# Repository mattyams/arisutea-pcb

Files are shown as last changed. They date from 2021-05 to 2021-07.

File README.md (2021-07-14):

# Arisutea - Arisu Keyboard PCB with More Modifications...now with MORE!
<p align="center">
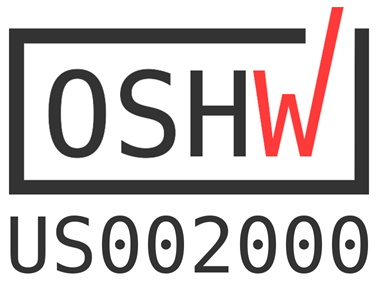
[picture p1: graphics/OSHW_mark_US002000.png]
  
</p>

### Arisutea Keyboard Variants
- [STM32](https://github.com/mattyams/arisutea-pcb-stm32) - Prototypes Received. STM32F072 MCU, board is being tested.
- [SK6812MiniE](https://github.com/mattyams/arisutea-pcb-rgb) - In Progress. PCB designed, just need to do some QC.
- [Bluetooth](https://github.com/mattyams/arisutea-pcb-bt) - In Progress. Initial design for the PCB is ongoing, need to research more on the MCU and batteries.

## Disclaimer: Use these files at your own risk.
アリステア PCB designed using KiCad. The layout was originally created by FateNozomi, inspired by Lyn's EM7 and TGR Alice with some modification. The layout was then modified by CorruptedJef and robotictomato to add USB-C, ESD and to shift/add some keys. This inspired me to modify the layout further by adding the ability to swap your switches out whenever you want and to make some keys a little more permenant. I have designed many boards in the past but never a keyboard so this is my first crack at it and I figured why not go all out? If you notice any issue please open an issue and we can discuss!

Since the layout has been modified yet again I decided to give the project a new name, Arisutea, which translates to Alistair. Obviously keeping the theme running here. 

Check out the iBOM [here](https://htmlpreview.github.io/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)! This was generated with [InteractiveHtmlBom](https://github.com/openscopeproject/InteractiveHtmlBom)!

Key modifications to the PCB:
- Added in Kailh Hotswap sockets.
- Addition of full backspace position, connected to switch 59 (row 0, column 13).
  - Removed switch 63 and repositioned switch 59 to add full backspace position.
- USB-C ESD rework.
- Added underglow LED strip support (v0.6+)
- Added LED indicators for CAPS and NUM lock as well as layer. (v0.6+)
- Updated JSON layout file for this particular keyboard.
- Original mounting holes have been returned to their rightful place. The idea of widening them was good at the time for FR4 plates, but not very practical. I am redesigning the case to allow for brass inserts and standoffs to be installed so the PCB will be nice and snug. More on that later. FR4 plates still will work but you will have to drill the holes out manually. If you take this route....go forth cautiously adventurer.

Renders generated by [Tracespace](https://github.com/tracespace/tracespace).
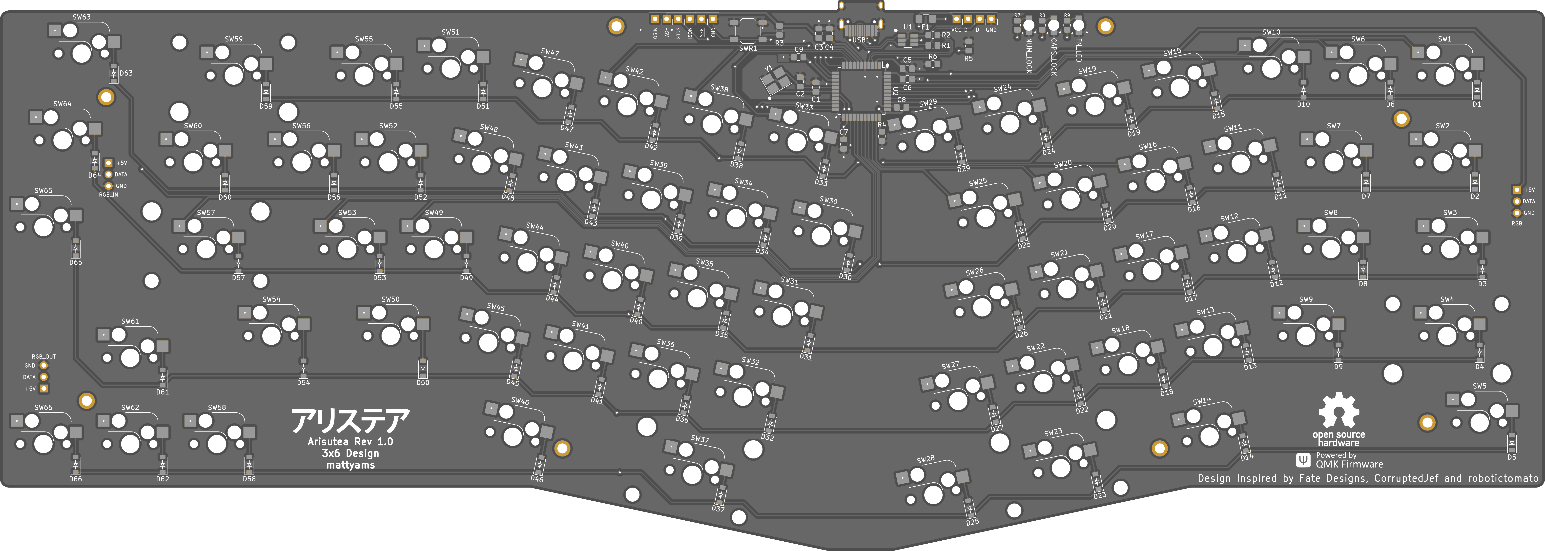
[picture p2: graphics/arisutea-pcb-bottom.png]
Arisutea

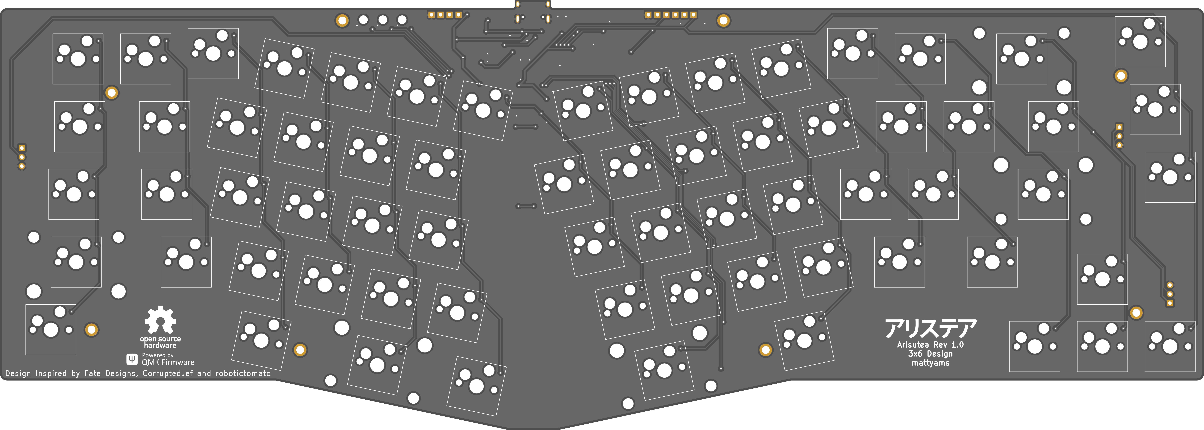
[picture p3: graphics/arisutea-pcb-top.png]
Arisutea-top

Arisutea-assembled
v0.6+
Arisutea-v0.6
Arisutea-v0.6-back

Just some recent builds...
Arisutea-builds
Arisutea-builds
Arisutea-builds

Messing around with different switches.
Arisutea-switches

# QMK Firmware
This can be located in the [firmware](https://github.com/mattyams/arisutea-pcb/tree/master/firmware) folder. 

# Case Files for Ponoko

Case files are updated to reflect changes to the full backspace on switch 59 and can be found in the hardware folder under [arisutea-case](https://github.com/mattyams/arisutea-pcb/tree/master/hardware/arisutea-case).  The case I ordered with these changes just came in this week (3/6/2021) and it works very well with the changes I made to the full backspace and addition of the stablizer on the prototypes designed by CorruptedJef and robotictomato. There is now a "boxed" version of the case that I have made that is designed to work with some wrist rests that do not have the ortho shape AND case files for version 0.6+ PCBs that include the indicator LEDs, I have not ordered/tested these but will soon.

Ponoko-case-1
Ponoko-case-2
Ponoko-case-3
Ponoko-case-4

# FR4 Plates and Case

Additionaly I have created files for FR4 plates to be made and used with this layout. These can be found in the hardware folder under [FR4_Plates](https://github.com/mattyams/arisutea-pcb/tree/master/hardware/FR4_Plates). The plates are designed to fit with the full backspace and non-stepped capslock. That being said, these will not work on the original Fate Designs PCB. No plans to create plates for the LED indicators on the v0.6+ PCBs. NOTE FOR v0.6.3+ PCBs! FR4 plates still will work but you will have to drill the holes out manually. If you take this route....go forth cautiously adventurer.

FR4-Plates-1
FR4-Plates-2
FR4-Plates-3
FR4-Plates-6

## Exceprts from original designer, FateNozomi:

Key differences:
- Removed the extra [B] key on the right half and shifted the [NM,.?] row to the left by 0.25U.
- Shifted the 3 keys to the right and added arrow keys.
- Tweaked the bottom so that the 1.5U keys doesn't protrude out a little.

Shifting the [NM,.?] row to the left by 0.25U required quite some work on the arrangement of keys for the right half.
As a result, this does not give the same typing experience as Lyn's EM7 and TGR Alice.
Lyn's EM7 and TGR Alice uses the home row as the center point to vertically align both halves while I used the number row instead.
Due to the nature of staggered keyboards, aligning using the number row resulted in the home row not being aligned.

Disclaimer: Use these files at your own risk.

## Gerber Files
Download the gerber files under [releases](https://github.com/mattyams/arisutea-pcb/releases).

## PCB Assembly
For the components required, you may refer to the bill of materials included along with the release as reference or load up the design file in KiCad.
All the components can be soldered using a regular soldering iron, though soldering the USB-C receptacle might be the biggest hurdle. I have made an adjustment to the USB footprint to allow for a little more error when handsoldering. POS files have been removed due to the overwhelming amount of compatibility issues of placement and selection. The BOM will remain for part numbers from LCSC and board placement.

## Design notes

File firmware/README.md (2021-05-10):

# QMK Firmware for Arisutea Keyboard

There are 2 files here and are described below:
- arisutea_rev2_default.hex - this is for the rev06 board that has the indicators and underglow LEDs. It uses the default layout seen below.
- arisutea_rev1_default.hex - this is for any board prior to rev06 that does not have any LEDs on the board at all. It uses the default layout seen below.

Layer 0
Arisutea-Layer-0
Layer 1 - STD will not include RGB keys
Arisutea-Layer-1

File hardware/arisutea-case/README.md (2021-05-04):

# Acrylic Case for Arisutea
アリステア Acrylic Case design formatted ready for Ponoko with the kerf of the switch cutout set to 0.15mm. Case files are updated to reflect changes to the full backspace on switch 59 and have the Arisutea logo engraved on the case. Removed the matte file and adjust the normal so you can use it for either one.

A "boxed" version of the case that I have made is designed to work with some wrist rests that do not have the ortho shape. 

There are now case files for v0.6 PCB that include the indicator LEDs, I have not ordered/tested these but will soon.

These files are a fork from FateNozomi's Arisu case which can be found [HERE](https://github.com/FateNozomi/arisu-case)

## Disclaimer: Use these files at your own risk. 

Ponoko-case-1
Ponoko-case-2
Ponoko-case-3
Ponoko-case-4

## Case Pieces for Angled Case!

- Low Profile Angled Case (arisutea_lopro_case_P2_ponoko.eps)
- High Profile Angled Layer (Optional) (arisutea_hipro_layer_P2_ponoko.eps)

## Case Pieces for Boxed Case!

- Low Profile Boxed Case (arisutea_lopro_case_P2_boxed_ponoko.eps)
- High Profile Boxed Layer (Optional) (arisutea_hipro_layer_P2_boxed_ponoko.eps)

Boxed-case-proto-1
Boxed-case-proto-2

## Case Pieces for v0.6 with LED indicator cutouts - PROTOTYPE!
#### Case Pieces for Boxed Case!
- Low Profile Angled Case with LED cutouts (arisutea_lopro_case_indicators_P2_ponoko.eps)
- High Profile Angled Layer with LED cutouts (Optional) (arisutea_hipro_layer_indicators_P2_ponoko.eps)

#### Case Pieces for Boxed Case!
- Low Profile Boxed Case with LED cutouts (arisutea_lopro_case_P2_boxed_indicators_ponoko.eps)
- High Profile Boxed Layer with LED cutouts (Optional) (arisutea_hipro_layer_P2_boxed_indicators_ponoko.eps)

## Fabrication

- Upload the .eps file to Ponoko and select P2 size 3mm acrylic with the color of your choice.
    - Remember if choosing to use matte colors you must upload the matte file!

## Assembly

#### For Low Profile

Material | Quantity
------------ | -------------
M2.5 * 12mm | 4
M2.5 * 5mm | 12
[M2.5 HARWIN R25-1000602 standoff](https://www.harwin.com/products/R25-1000602/) | 8

#### For High Profile

Material | Quantity
------------ | -------------
M2.5 * 12mm | 12
M2.5 * 5mm | 4
[M2.5 HARWIN R25-1000602 standoff](https://www.harwin.com/products/R25-1000602/) | 8

This design uses M2.5 screws and standoffs. Feel free to modify the screw and standoff hole design accommodate your needs.  
The case will sit at an angle with the center portion protruding out so test the placement of your rubber bumpons before sticking them.

high profile side  
low profile side

Ponoko-case-3
Ponoko-case-4

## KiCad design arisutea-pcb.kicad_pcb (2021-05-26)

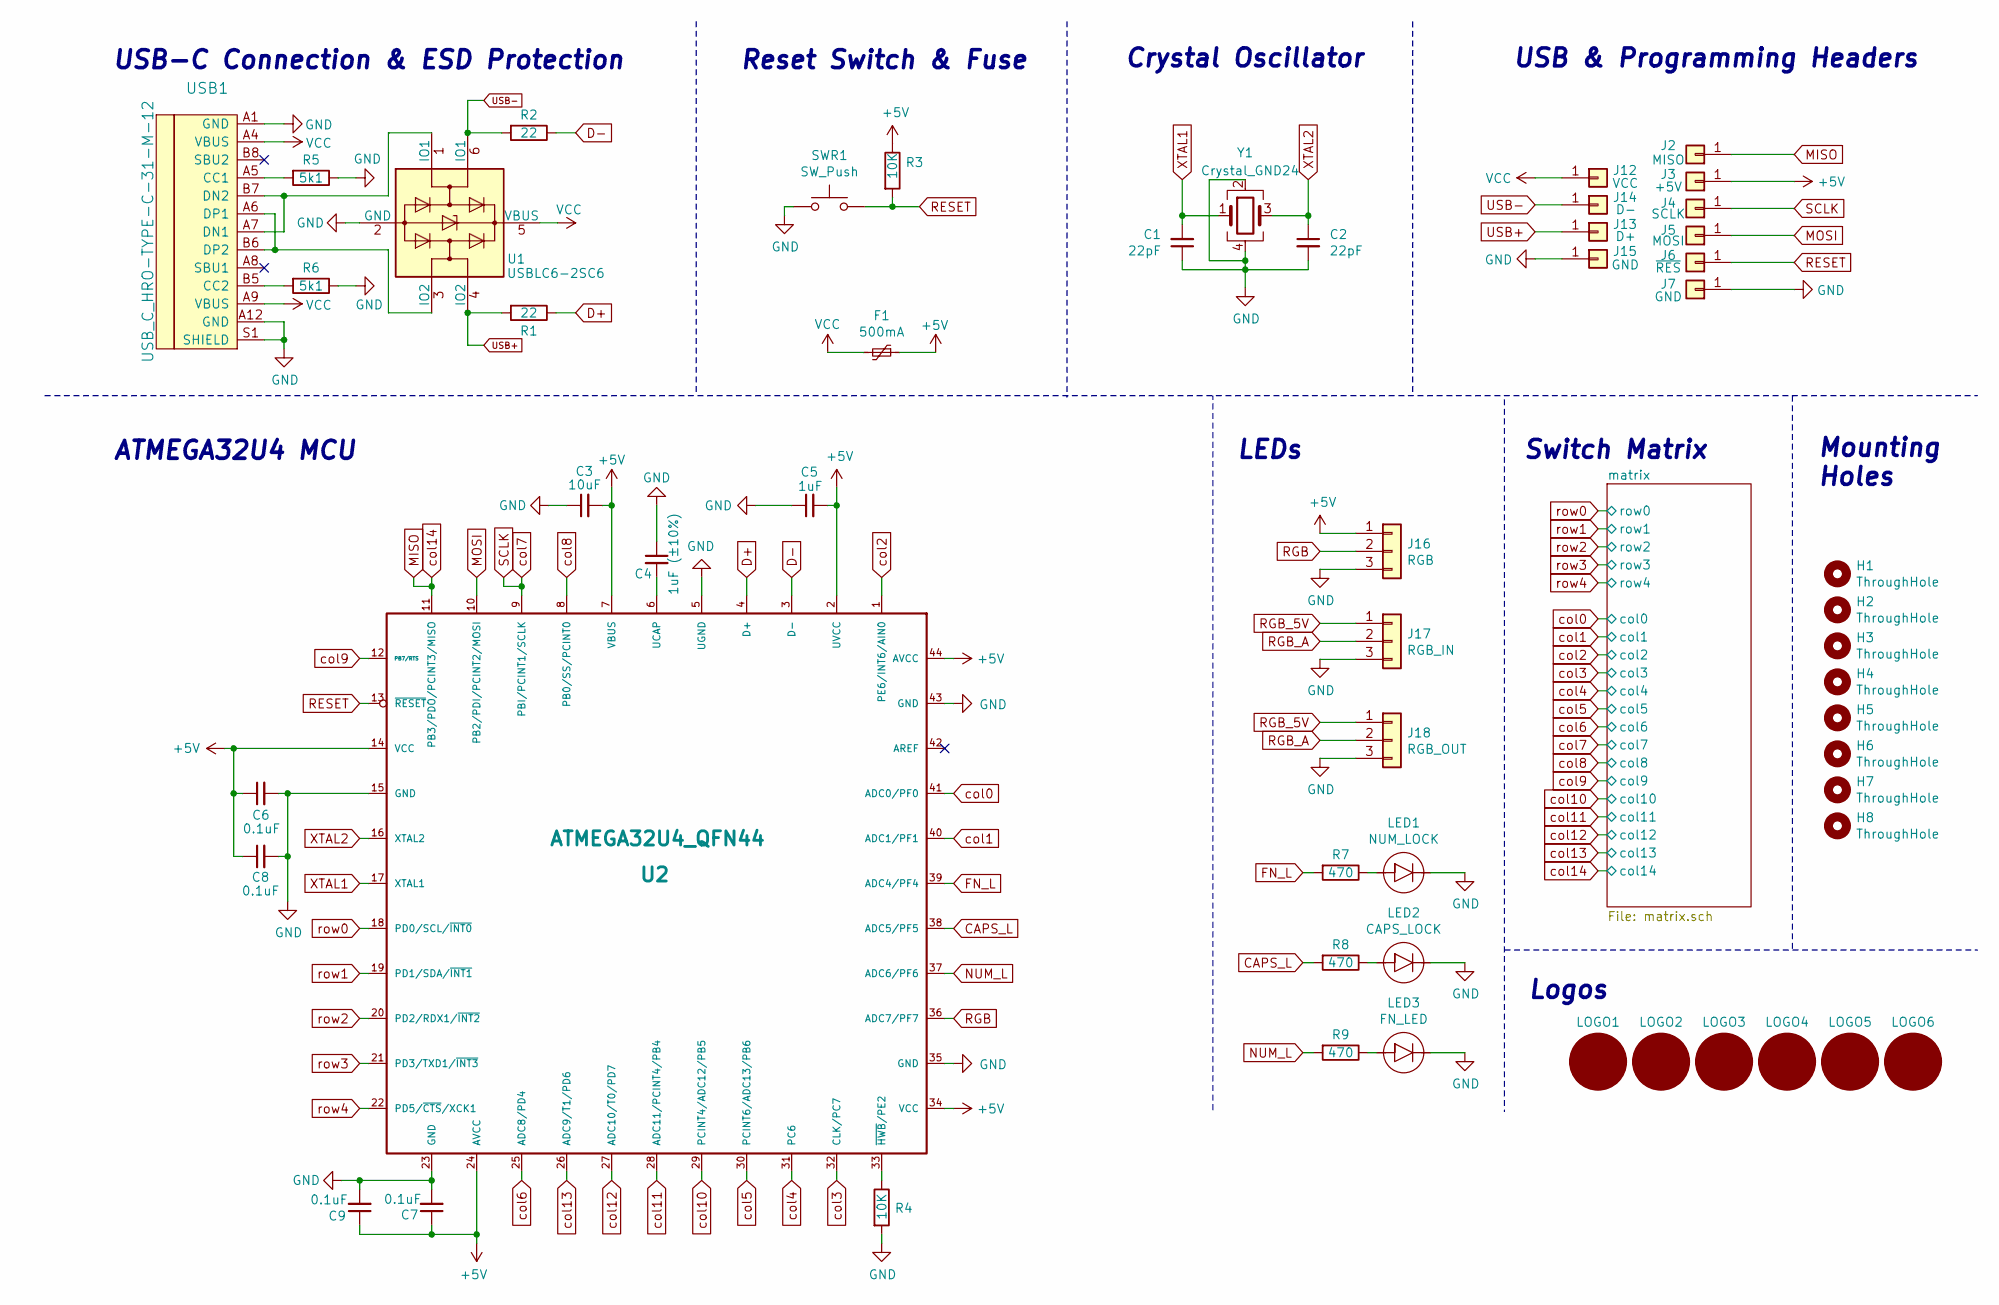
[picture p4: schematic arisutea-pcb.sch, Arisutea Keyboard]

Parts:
C1, C2: 22pF; C_0805_2012Metric_Pad1.18x1.45mm_HandSolder; LCSC C1804
C3: 10uF; C_0805_2012Metric_Pad1.18x1.45mm_HandSolder; LCSC C15850
C4: 1uF (±10%); C_0805_2012Metric_Pad1.18x1.45mm_HandSolder; LCSC C28323
C5: 1uF; C_0805_2012Metric_Pad1.18x1.45mm_HandSolder; LCSC C28323
C6, C7, C8, C9: 0.1uF; C_0805_2012Metric_Pad1.18x1.45mm_HandSolder; LCSC C28233
F1: 500mA; Fuse_1206_3216Metric_Pad1.42x1.75mm_HandSolder; LCSC C70068
H1, H2, H3, H4, H5, H6, H7, H8: ThroughHole; Generic-Mounthole
J2: MISO; PinHeader_1x01_P2.54mm_Vertical
J3: +5V; PinHeader_1x01_P2.54mm_Vertical
J4: SCLK; PinHeader_1x01_P2.54mm_Vertical
J5: MOSI; PinHeader_1x01_P2.54mm_Vertical
J6: ~RES~; PinHeader_1x01_P2.54mm_Vertical
J7, J15: GND; PinHeader_1x01_P2.54mm_Vertical
J12: VCC; PinHeader_1x01_P2.54mm_Vertical
J13: D+; PinHeader_1x01_P2.54mm_Vertical
J14: D-; PinHeader_1x01_P2.54mm_Vertical
J16: RGB; PinHeader_1x03_P2.54mm_Vertical
J17: RGB_IN; PinHeader_1x03_P2.54mm_Vertical
J18: RGB_OUT; PinHeader_1x03_P2.54mm_Vertical
LED1: NUM_LOCK; LED_IN-S124ARUW; LCSC C401114
LED2: CAPS_LOCK; LED_IN-S124ARUW; LCSC C401114
LED3: FN_LED; LED_IN-S124ARUW; LCSC C401114
LOGO1, LOGO2: arisutea_logo
LOGO3, LOGO4: QMK Logo; OSHW-Logo_11.4x12mm_SilkScreen
LOGO5, LOGO6: QMK_Logo_Light
R1, R2: 22; R_0805_2012Metric_Pad1.20x1.40mm_HandSolder; LCSC C17561
R3, R4: 10K; R_0805_2012Metric_Pad1.20x1.40mm_HandSolder; LCSC C17414
R5, R6: 5k1; R_0805_2012Metric_Pad1.20x1.40mm_HandSolder; LCSC C27834
R7, R8, R9: 470; R_0805_2012Metric_Pad1.20x1.40mm_HandSolder; LCSC C27834
SWR1: SW_Push; SW_SPST_TL3342; LCSC C318884
U1: USBLC6-2SC6; SOT-23-6_Handsoldering; LCSC C7519
U2: ATMEGA32U4_QFN44; TQFP-44_10x10mm_P0.8mm; LCSC C44854
USB1: USB_C_HRO-TYPE-C-31-M-12; USB_C_Receptacle_HRO_TYPE-C-31-M-12-HandSoldering; LCSC C319148
Y1: Crystal_GND24; Crystal_SMD_TXC_7M-4Pin_3.2x2.5mm_HandSoldering; LCSC C89371

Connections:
+5V: C3.2, C5.2, C6.1, C7.1, C8.1, C9.1, F1.1, J3.1, J16.1, R3.1, U2.2 (UVCC), U2.7 (VBUS), U2.14 (VCC), U2.24 (AVCC), U2.34 (VCC), U2.44 (AVCC)
CAPS_L: R8.2, U2.38 (ADC5/PF5)
D+: R1.1, U2.4 (D+)
D-: R2.1, U2.3 (D-)
FN_L: R7.2, U2.39 (ADC4/PF4)
GND: C1.1, C2.2, C3.1, C4.1, C5.1, C6.2, C7.2, C8.2, C9.2, J7.1, J15.1, J16.3, J17.3, J18.3, LED1.C, LED2.C, LED3.C, R4.2, R5.1, R6.1, SWR1.1, U1.2 (GND), U2.5 (UGND), U2.15 (GND), U2.23 (GND), U2.35 (GND), U2.43 (GND), USB1.A1 (GND), USB1.A12 (GND), USB1.S1 (SHIELD), Y1.2, Y1.4
MISO: J2.1, U2.11 (PB3/PDO/PCINT3/MISO); also elsewhere on the board
MOSI: J5.1, U2.10 (PB2/PDI/PCINT2/MOSI)
NUM_L: R9.2, U2.37 (ADC6/PF6)
unnamed: C4.2, U2.6 (UCAP)
unnamed: LED1.A, R7.1
unnamed: LED2.A, R8.1
unnamed: LED3.A, R9.1
unnamed: R4.1, U2.33 (~HWB~/PE2)
unnamed: R5.2, USB1.A5 (CC1)
unnamed: R6.2, USB1.B5 (CC2)
unnamed: U1.1 (IO1), USB1.A7 (DN1), USB1.B7 (DN2)
unnamed: U1.3 (IO2), USB1.A6 (DP1), USB1.B6 (DP2)
RESET: J6.1, R3.2, SWR1.2, U2.13 (~RESET~)
RGB: J16.2, U2.36 (ADC7/PF7)
RGB_5V: J17.1, J18.1
RGB_A: J17.2, J18.2
SCLK: J4.1, U2.9 (PBI/PCINT1/SCLK); also elsewhere on the board
USB+: J13.1, R1.2, U1.4 (IO2)
USB-: J14.1, R2.2, U1.6 (IO1)
VCC: F1.2, J12.1, U1.5 (VBUS), USB1.A4 (VBUS), USB1.A9 (VBUS)
XTAL1: C1.2, U2.17 (XTAL1), Y1.1
XTAL2: C2.1, U2.16 (XTAL2), Y1.3
col0: U2.41 (ADC0/PF0); also elsewhere on the board
col1: U2.40 (ADC1/PF1); also elsewhere on the board
col2: U2.1 (PE6/INT6/AIN0); also elsewhere on the board
col3: U2.32 (CLK/PC7); also elsewhere on the board
col4: U2.31 (PC6); also elsewhere on the board
col5: U2.30 (PCINT6/ADC13/PB6); also elsewhere on the board
col6: U2.25 (ADC8/PD4); also elsewhere on the board
col8: U2.8 (PB0/SS/PCINT0); also elsewhere on the board
col9: U2.12 (PB7/RTS); also elsewhere on the board
col10: U2.29 (PCINT4/ADC12/PB5); also elsewhere on the board
col11: U2.28 (ADC11/PCINT4/PB4); also elsewhere on the board
col12: U2.27 (ADC10/T0/PD7); also elsewhere on the board
col13: U2.26 (ADC9/T1/PD6); also elsewhere on the board
row0: U2.18 (PD0/SCL/~INT0~); also elsewhere on the board
row1: U2.19 (PD1/SDA/~INT1~); also elsewhere on the board
row2: U2.20 (PD2/RDX1/~INT2~); also elsewhere on the board
row3: U2.21 (PD3/TXD1/~INT3~); also elsewhere on the board
row4: U2.22 (PD5/~CTS~/XCK1); also elsewhere on the board

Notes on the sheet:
ATMEGA32U4 MCU
USB-C Connection & ESD Protection
Reset Switch & Fuse
Crystal Oscillator
USB & Programming Headers
LEDs
Switch Matrix
Logos
Mounting Holes

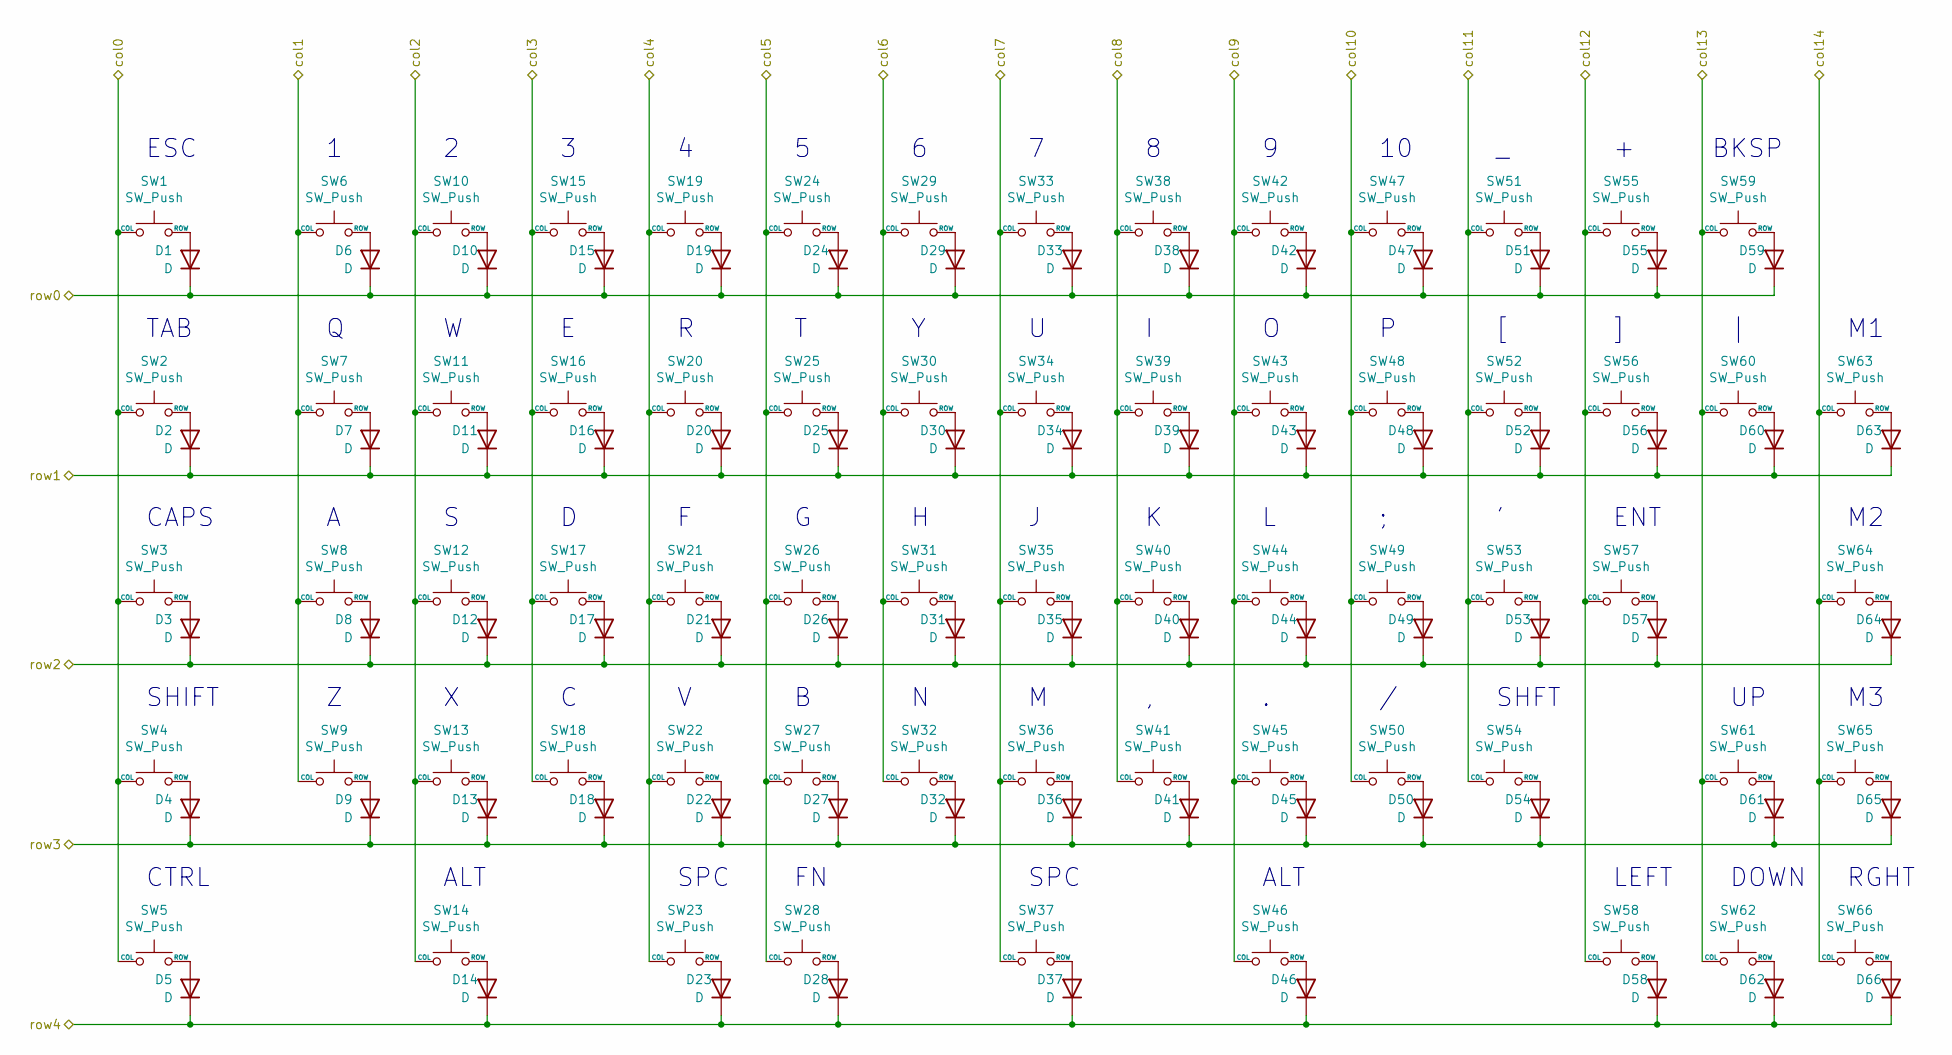
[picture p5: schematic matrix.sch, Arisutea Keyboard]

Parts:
D1, D2, D3, D4, D5, D6, D7, D8, D9, D10, D11, D12, D13, D14, D15, D16, D17, D18, D19, D20, D21, D22, D23, D24, D25, D26, D27, D28, D29, D30, D31, D32, D33, D34, D35, D36, D37, D38, D39, D40, D41, D42, D43, D44, D45, D46, D47, D48, D49, D50, D51, D52, D53, D54, D55, D56, D57, D58, D59, D60, D61, D62, D63, D64, D65, D66: D; D_SOD-123; LCSC C81598
SW1, SW6, SW7, SW8, SW9, SW10, SW11, SW12, SW13, SW14, SW15, SW16, SW17, SW18, SW19, SW20, SW21, SW22, SW24, SW25, SW26, SW27, SW28, SW29, SW30, SW31, SW32, SW33, SW34, SW35, SW36, SW38, SW39, SW40, SW41, SW42, SW43, SW44, SW45, SW46, SW47, SW48, SW49, SW50, SW51, SW52, SW53, SW55, SW56, SW58, SW61, SW62, SW63, SW64, SW65, SW66: SW_Push; SW_Hotswap_Kailh_1.00u
SW2, SW5, SW60: SW_Push; SW_Hotswap_Kailh_1.50u
SW3, SW54: SW_Push; SW_Hotswap_Kailh_1.75u
SW4: SW_Push; SW_Hotswap_Kailh_2.25u
SW23: SW_Push; SW_Hotswap_Kailh_2.00u_RevStab
SW37: SW_Push; SW_Hotswap_Kailh_2.75u_RevStab
SW57: SW_Push; SW_Hotswap_Kailh_2.25u_RevStab
SW59: SW_Push; SW_Hotswap_Kailh_2.00u

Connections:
MISO: SW63.1 (COL), SW64.1 (COL), SW65.1 (COL), SW66.1 (COL); also elsewhere on the board
unnamed: D1.2 (A), SW1.2 (ROW)
unnamed: D2.2 (A), SW2.2 (ROW)
unnamed: D3.2 (A), SW3.2 (ROW)
unnamed: D4.2 (A), SW4.2 (ROW)
unnamed: D5.2 (A), SW5.2 (ROW)
unnamed: D6.2 (A), SW6.2 (ROW)
unnamed: D7.2 (A), SW7.2 (ROW)
unnamed: D8.2 (A), SW8.2 (ROW)
unnamed: D9.2 (A), SW9.2 (ROW)
unnamed: D10.2 (A), SW10.2 (ROW)
unnamed: D11.2 (A), SW11.2 (ROW)
unnamed: D12.2 (A), SW12.2 (ROW)
unnamed: D13.2 (A), SW13.2 (ROW)
unnamed: D14.2 (A), SW14.2 (ROW)
unnamed: D15.2 (A), SW15.2 (ROW)
unnamed: D16.2 (A), SW16.2 (ROW)
unnamed: D17.2 (A), SW17.2 (ROW)
unnamed: D18.2 (A), SW18.2 (ROW)
unnamed: D19.2 (A), SW19.2 (ROW)
unnamed: D20.2 (A), SW20.2 (ROW)
unnamed: D21.2 (A), SW21.2 (ROW)
unnamed: D22.2 (A), SW22.2 (ROW)
unnamed: D23.2 (A), SW23.2 (ROW)
unnamed: D24.2 (A), SW24.2 (ROW)
unnamed: D25.2 (A), SW25.2 (ROW)
unnamed: D26.2 (A), SW26.2 (ROW)
unnamed: D27.2 (A), SW27.2 (ROW)
unnamed: D28.2 (A), SW28.2 (ROW)
unnamed: D29.2 (A), SW29.2 (ROW)
unnamed: D30.2 (A), SW30.2 (ROW)
unnamed: D31.2 (A), SW31.2 (ROW)
unnamed: D32.2 (A), SW32.2 (ROW)
unnamed: D33.2 (A), SW33.2 (ROW)
unnamed: D34.2 (A), SW34.2 (ROW)
unnamed: D35.2 (A), SW35.2 (ROW)
unnamed: D36.2 (A), SW36.2 (ROW)
unnamed: D37.2 (A), SW37.2 (ROW)
unnamed: D38.2 (A), SW38.2 (ROW)
unnamed: D39.2 (A), SW39.2 (ROW)
unnamed: D40.2 (A), SW40.2 (ROW)
unnamed: D41.2 (A), SW41.2 (ROW)
unnamed: D42.2 (A), SW42.2 (ROW)
unnamed: D43.2 (A), SW43.2 (ROW)
unnamed: D44.2 (A), SW44.2 (ROW)
unnamed: D45.2 (A), SW45.2 (ROW)
unnamed: D46.2 (A), SW46.2 (ROW)
unnamed: D47.2 (A), SW47.2 (ROW)
unnamed: D48.2 (A), SW48.2 (ROW)
unnamed: D49.2 (A), SW49.2 (ROW)
unnamed: D50.2 (A), SW50.2 (ROW)
unnamed: D51.2 (A), SW51.2 (ROW)
unnamed: D52.2 (A), SW52.2 (ROW)
unnamed: D53.2 (A), SW53.2 (ROW)
unnamed: D54.2 (A), SW54.2 (ROW)
unnamed: D55.2 (A), SW55.2 (ROW)
unnamed: D56.2 (A), SW56.2 (ROW)
unnamed: D57.2 (A), SW57.2 (ROW)
unnamed: D58.2 (A), SW58.2 (ROW)
unnamed: D59.2 (A), SW59.2 (ROW)
unnamed: D60.2 (A), SW60.2 (ROW)
unnamed: D61.2 (A), SW61.2 (ROW)
unnamed: D62.2 (A), SW62.2 (ROW)
unnamed: D63.2 (A), SW63.2 (ROW)
unnamed: D64.2 (A), SW64.2 (ROW)
unnamed: D65.2 (A), SW65.2 (ROW)
unnamed: D66.2 (A), SW66.2 (ROW)
SCLK: SW33.1 (COL), SW34.1 (COL), SW35.1 (COL), SW36.1 (COL), SW37.1 (COL); also elsewhere on the board
col0: SW1.1 (COL), SW2.1 (COL), SW3.1 (COL), SW4.1 (COL), SW5.1 (COL); also elsewhere on the board
col1: SW6.1 (COL), SW7.1 (COL), SW8.1 (COL), SW9.1 (COL); also elsewhere on the board
col2: SW10.1 (COL), SW11.1 (COL), SW12.1 (COL), SW13.1 (COL), SW14.1 (COL); also elsewhere on the board
col3: SW15.1 (COL), SW16.1 (COL), SW17.1 (COL), SW18.1 (COL); also elsewhere on the board
col4: SW19.1 (COL), SW20.1 (COL), SW21.1 (COL), SW22.1 (COL), SW23.1 (COL); also elsewhere on the board
col5: SW24.1 (COL), SW25.1 (COL), SW26.1 (COL), SW27.1 (COL), SW28.1 (COL); also elsewhere on the board
col6: SW29.1 (COL), SW30.1 (COL), SW31.1 (COL), SW32.1 (COL); also elsewhere on the board
col8: SW38.1 (COL), SW39.1 (COL), SW40.1 (COL), SW41.1 (COL); also elsewhere on the board
col9: SW42.1 (COL), SW43.1 (COL), SW44.1 (COL), SW45.1 (COL), SW46.1 (COL); also elsewhere on the board
col10: SW47.1 (COL), SW48.1 (COL), SW49.1 (COL), SW50.1 (COL); also elsewhere on the board
col11: SW51.1 (COL), SW52.1 (COL), SW53.1 (COL), SW54.1 (COL); also elsewhere on the board
col12: SW55.1 (COL), SW56.1 (COL), SW57.1 (COL), SW58.1 (COL); also elsewhere on the board
col13: SW59.1 (COL), SW60.1 (COL), SW61.1 (COL), SW62.1 (COL); also elsewhere on the board
row0: D1.1 (K), D6.1 (K), D10.1 (K), D15.1 (K), D19.1 (K), D24.1 (K), D29.1 (K), D33.1 (K), D38.1 (K), D42.1 (K), D47.1 (K), D51.1 (K), D55.1 (K), D59.1 (K); also elsewhere on the board
row1: D2.1 (K), D7.1 (K), D11.1 (K), D16.1 (K), D20.1 (K), D25.1 (K), D30.1 (K), D34.1 (K), D39.1 (K), D43.1 (K), D48.1 (K), D52.1 (K), D56.1 (K), D60.1 (K), D63.1 (K); also elsewhere on the board
row2: D3.1 (K), D8.1 (K), D12.1 (K), D17.1 (K), D21.1 (K), D26.1 (K), D31.1 (K), D35.1 (K), D40.1 (K), D44.1 (K), D49.1 (K), D53.1 (K), D57.1 (K), D64.1 (K); also elsewhere on the board
row3: D4.1 (K), D9.1 (K), D13.1 (K), D18.1 (K), D22.1 (K), D27.1 (K), D32.1 (K), D36.1 (K), D41.1 (K), D45.1 (K), D50.1 (K), D54.1 (K), D61.1 (K), D65.1 (K); also elsewhere on the board
row4: D5.1 (K), D14.1 (K), D23.1 (K), D28.1 (K), D37.1 (K), D46.1 (K), D58.1 (K), D62.1 (K), D66.1 (K); also elsewhere on the board

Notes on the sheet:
ESC
TAB
ENT
RGHT
LEFT
DOWN
SPC
ALT
CTRL
SHFT
SHIFT
CAPS
BKSP

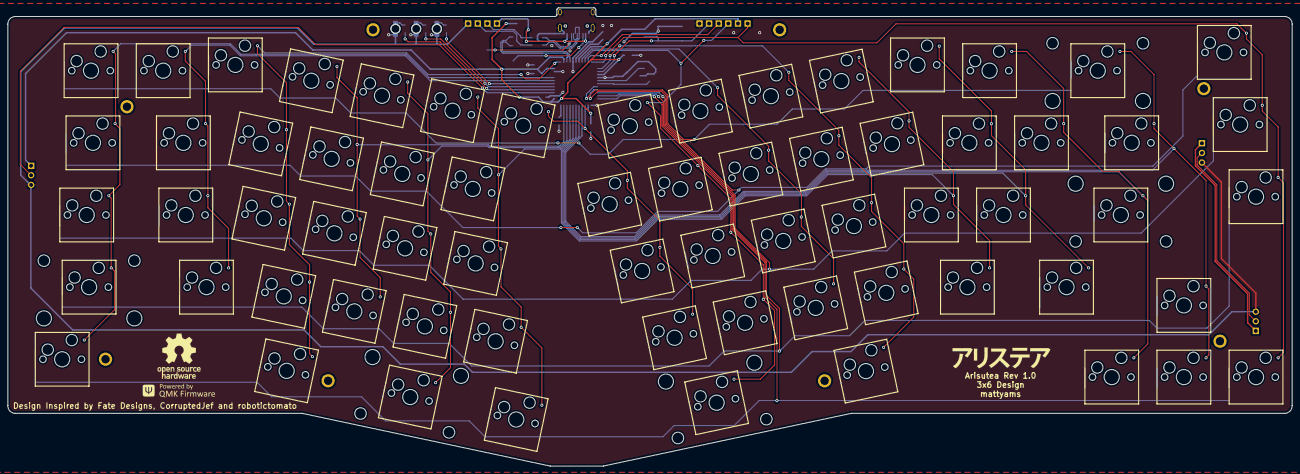
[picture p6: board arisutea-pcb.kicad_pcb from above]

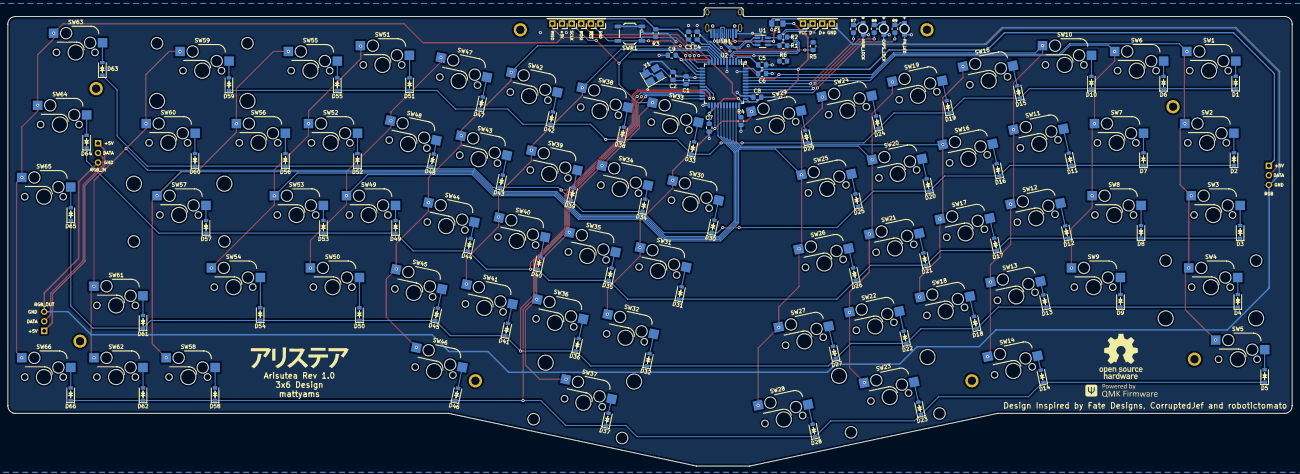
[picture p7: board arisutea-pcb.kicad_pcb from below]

Board: 2 copper layers, 339.1 x 121.0 mm, 186 parts (109 on the bottom side), 112 nets.

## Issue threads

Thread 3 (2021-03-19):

Arisutea plate compatibility

ctlrome, 2021-03-19:
Is the arisutea plate compatible with the arisu case?

mattyams, 2021-03-22:
I haven't forgotten about this, just waiting on the extra acrylic case to show up this week so I can test it without having to disassemble my current board that is already built.

ctlrome, 2021-03-22:
Sorry for the bombardment of questions, but does the PCB mount to the plate
in any way (besides the switches). I had some hotswap boards that fell from
under the switches since nothing else was holding them together.

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

mattyams, 2021-03-24:
No worries! So the case came in and I confirmed that the FR4 plate does fit above the PCB and under the acrylic switch plate, however, the 3mm thickness of the acrylic switch plate renders the FR4 plate useless.  The FR4 plate makes no contact with the switches nor will provide any further "support" to PCB or otherwise.

BUT! During the assembly of the Arisutea PCB into the Arisutea acrylic case I observed that adding the hot swap sockets to the PCB adds some height to the PCB itself which in turn allows the PCB to rest comfortably on the bottom acrylic plate and is not floating like I had previously thought it would once switches are inserted into the case and PCB.

I hope this helps and answers your question. Please feel free to inquire further if you have anymore questions.

ctlrome, 2021-03-24:
Thank you so much! I was thinking about getting a couple of arisutea PCBs
and plates, but I'm gonna wait until you release the final version. Keep up
the good work!

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

mattyams, 2021-03-25:
So I did a little more work on this and found that when I was originally testing this for you that I did not have all the pieces in place for the hipro case. You can do this however the hardware changes (standoffs need to be shorter) and the case is a 3mm shorter. If you don't want to do that then get some of this foam (https://smile.amazon.com/gp/product/B07BL296HK/) or something similar in 2mm or 3mm and use the PCB as a template to cut a piece to place under the PCB in the case. This will do 2 things. 1. It will help with acoustics and 2. It will assist in PCB support when installing/replacing switches after assembly.

ctlrome, 2021-03-25:
That’s convenient since I ordered a bunch of eva foam from ponoko with the
case so I’ll just use that. Thanks for letting me know.

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

Closed 2021-03-25.

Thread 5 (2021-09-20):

CPL / Positioning file for v1.0?

scrthq, 2021-09-20:
Heyo! Thank you for this fork!!! I'm looking to have some PCB's printed, but JLCPCB needs the CPL file for SMT assembly. I can see it on some older releases, but not sure if that will line up for the 1.0 release offhand.

Is there a link to the correct CPL / positioning file for the 1.0 release?

Thanks again!!

scrthq, 2021-09-20:
Bah, just seeing the bottom of the readme =\... No worries, thanks for the design update!!

Closed 2021-09-20.

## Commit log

2021-05-04 v0.6.3
    - Updated mounting holes for new case design.
    - Removed matte case as the regular file can be used for either.
    - Library update.
    - Gerbies regenerated for version bump.
    - iBOM added.
    - README for most pages edited.
    [arisutea-pcb.kicad_pcb, arisutea-pcb.sch, matrix.sch]
2021-05-22 Version 1.0 Release
    Release of version 1.
    - Libraries have been merged for easier access.
    - Moved one cap a little closer to the MCU.
    - Regenerated gerbies, BOM and POS files.
    - New iBOM.
    - Bumped version number.
    [arisutea-pcb.kicad_pcb, arisutea-pcb.sch, matrix.sch]
2021-05-25 case corrections
    Caught an error in the design of the lopro case that would duplicate the switch cutouts and cause the cost and/or cutting time to increase. Removed faulty lines and regenerated case files. :100:
2021-05-26 fixed USB net names
    [arisutea-pcb.kicad_pcb, arisutea-pcb.sch, matrix.sch]
2021-05-27 fixed another case error
2021-07-14 remove POS files for SMT assembly
    It was becoming apparent that there were too many placement issues with JLCPCB (and maybe other fab houses too) to warrant this file existing. I had made it as a courtesy but nearly everyone that has used it has reported issues. Despite my multiple attempts to correct the issue persisted. You can find the file in history but as a reminder, use these files at your own risk. I take no responsibility.
